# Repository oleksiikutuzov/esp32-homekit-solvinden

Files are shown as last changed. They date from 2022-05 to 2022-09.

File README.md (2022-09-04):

# esp32-homekit-led-strip
Native Apple HomeKit via an ESP32 for the IKEA SOLVINDEN lamp



Software is based on the [HomeSpan](https://github.com/HomeSpan/HomeSpan) library. Supports RGB or RGBW Neopixel LEDs.

_As usual, don't expect any warranties. I am just a hobbyist, not a professional. It works for me, but you take your own risk using it. I am not liable for any damage to your devices._

## Hardware

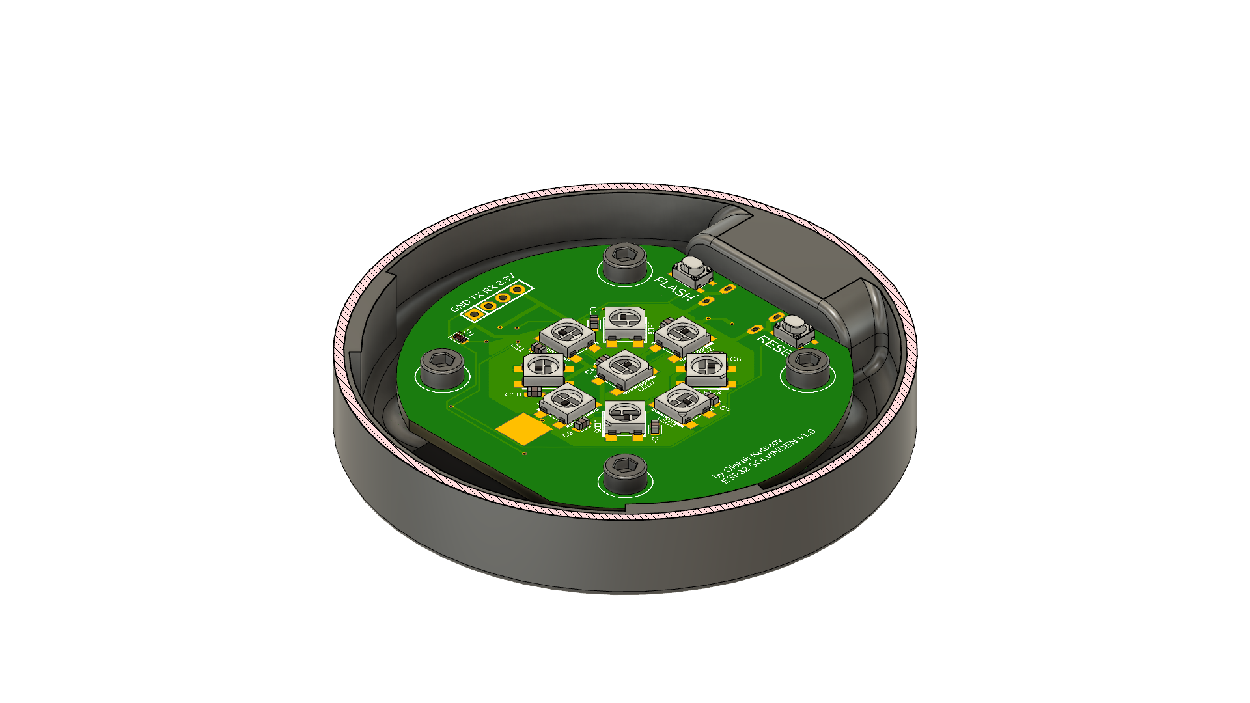
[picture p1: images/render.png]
render
 

Custom PCB is designed for the project as well as a replacement base for the lamp. The base has holes for M3 threaded inserts.

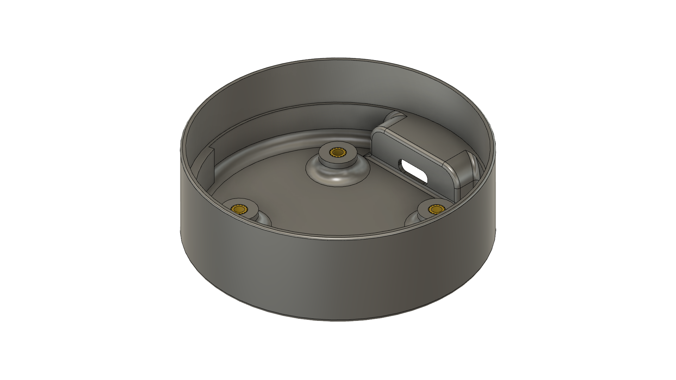
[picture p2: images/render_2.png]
render 2
 

From the original lamp, you only need the top part, which is good for diffusion. Be careful not to scratch it, as it sits pretty tight because the device is sealed.

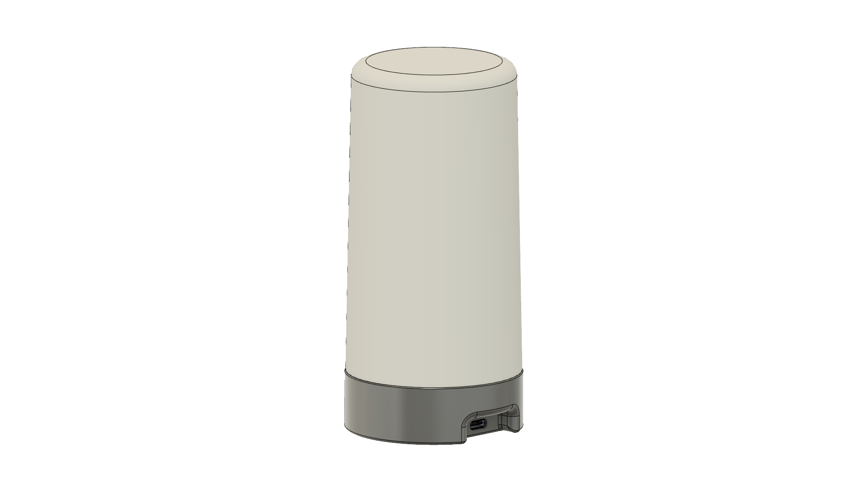
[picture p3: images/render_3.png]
render 3


## HomeKit functions

The device has two modes, which can be switched via the Eve app:
* Manual Control (manually set one single color)
* Rainbow (the device is changing colors)

*As they are custom characteristics, they are not visible in the Home app*

Characteristics values are saved to NVS, so they will be restored if the device loses power. 

## Software

Here you can see, which pins are used and pre-defined in the firmware:
```c++
 *                ESP-WROOM-32 Utilized pins
 *              ╔═════════════════════════════╗
 *              ║┌─┬─┐  ┌──┐  ┌─┐             ║
 *              ║│ | └──┘  └──┘ |             ║
 *              ║│ |            |             ║
 *              ╠═════════════════════════════╣
 *          +++ ║GND                       GND║ +++
 *          +++ ║3.3V                     IO23║ USED_FOR_NOTHING
 *              ║                         IO22║
 *              ║IO36                      IO1║ TX
 *              ║IO39                      IO3║ RX
 *              ║IO34                     IO21║
 *              ║IO35                         ║ NC
 *      RED_LED ║IO32                     IO19║
 *              ║IO33                     IO18║ 
 *              ║IO25                      IO5║
 *              ║IO26                     IO17║ NEOPIXEL
 *              ║IO27                     IO16║
 *              ║IO14                      IO4║
 *              ║IO12                      IO0║ +++, BUTTON
 *              ╚═════════════════════════════╝
```

The firmware can be built and flashed using the Arduino IDE.

For this, you will need to add ESP32 support to it.

Furthermore, you will also need to install the following libraries using the Library Manager:

* HomeSpan

And some libraries manually:

1. Go to this GitHub repo and download it as a ZIP - [ElegantOTA](https://github.com/ayushsharma82/ElegantOTA)
2. In Arduino IDE select "Sketch" -> "Include Library" and "Add .ZIP Library..." and select downloaded ZIP
3. Download and open this repository in Arduino IDE (or VSCode with Arduino extension)
4. Set the upload speed to 115200
5. Build, flash, and you're done

Instead of Arduino IDE OTA, the webserver update was implemented. You can flash binary at `http://[DEVICE IP]/update`.
There is a reboot link. Opening `http://[DEVICE IP]/reboot` will force the device to reboot. 

The device can also be controlled by the FLASH button on the board. More on [HomeSpan docs](https://github.com/HomeSpan/HomeSpan/blob/master/docs/UserGuide.md)

## Connect to HomeKit

1. Plug your LED Controller to power.
2. Press the FLASH button until the LED starts blinking rapidly and release it. Now it is in the configuration mode (More on [HomeSpan docs](https://github.com/HomeSpan/HomeSpan/blob/master/docs/UserGuide.md)). Press it two more times until the LED starts blinking 3 times in a row. This means mode 3 is chosen. Hold the button for 3-4 seconds once again and the WiFi AP will be started.
3. Go to WiFi settings on your iPhone/iPad and connect to the "HomeSpan-Setup" WiFi network.
4. You will choose your WiFi network and set the setup code for the accessory. 
5. Go to your Home app and select "Add Accessory"
6. Select "More Options" and you should see your LED Controller there.

## Todo

- [ ] Add physical button to control the device
- [ ] Add level shifter to the PCB for 5V on the data line for RGBW leds  

## References and sources

- @HomeSpan for ESP32 HomeKit firmware [GitHub link](https://github.com/HomeSpan/HomeSpan)

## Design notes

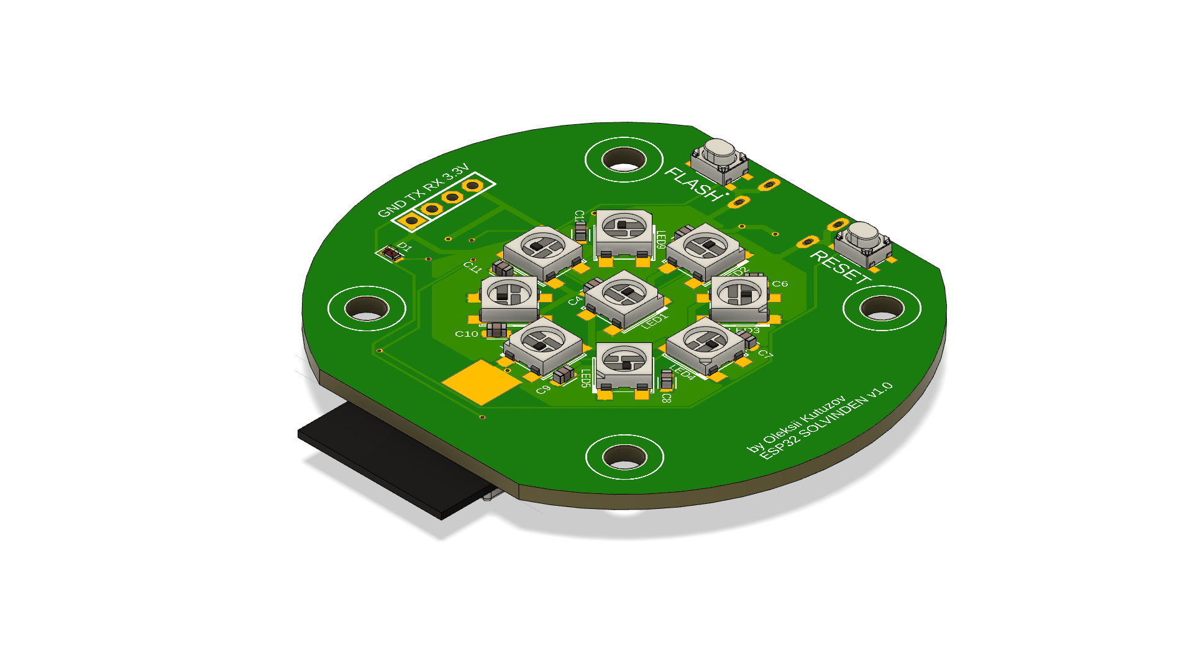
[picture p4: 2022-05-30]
PCB/PCB_TOP_1.0.png

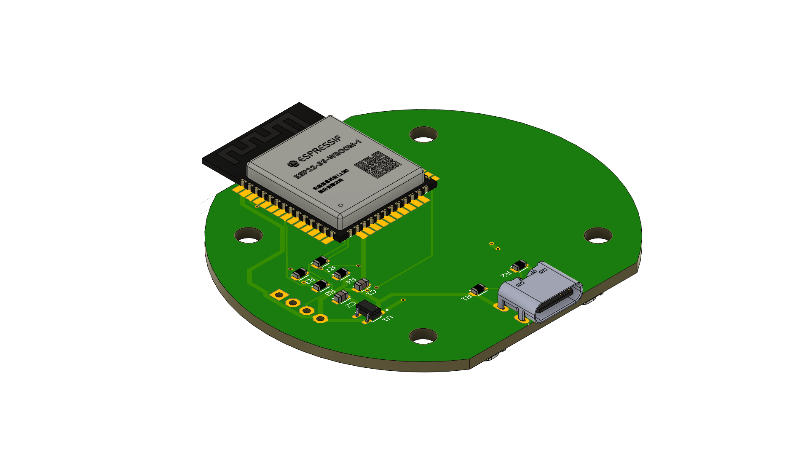
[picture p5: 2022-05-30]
PCB/PCB_BOTTOM_1.0.png

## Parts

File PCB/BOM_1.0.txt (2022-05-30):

Part Value             Device                   Package               Description                                                                  AVAILABILITY CATEGORY  
C1   10uF              C_CHIP-0603(1608-METRIC) CAPC1608X85           Capacitor - Generic                                                                       Capacitor 
C2   10uF              C_CHIP-0603(1608-METRIC) CAPC1608X85           Capacitor - Generic                                                                       Capacitor 
C4   0.1uF             C_CHIP-0603(1608-METRIC) CAPC1608X85           Capacitor - Generic                                                                       Capacitor 
C5   0.1uF             C_CHIP-0603(1608-METRIC) CAPC1608X85           Capacitor - Generic                                                                       Capacitor 
C6   0.1uF             C_CHIP-0603(1608-METRIC) CAPC1608X85           Capacitor - Generic                                                                       Capacitor 
C7   0.1uF             C_CHIP-0603(1608-METRIC) CAPC1608X85           Capacitor - Generic                                                                       Capacitor 
C8   0.1uF             C_CHIP-0603(1608-METRIC) CAPC1608X85           Capacitor - Generic                                                                       Capacitor 
C9   0.1uF             C_CHIP-0603(1608-METRIC) CAPC1608X85           Capacitor - Generic                                                                       Capacitor 
C10  0.1uF             C_CHIP-0603(1608-METRIC) CAPC1608X85           Capacitor - Generic                                                                       Capacitor 
C11  0.1uF             C_CHIP-0603(1608-METRIC) CAPC1608X85           Capacitor - Generic                                                                       Capacitor 
C12  0.1uF             C_CHIP-0603(1608-METRIC) CAPC1608X85           Capacitor - Generic                                                                       Capacitor 
D1   LED               CHIP-FLAT-R_0603-0.80MM  LEDC1608X80N_FLAT-R                                                                                             LED       
J1   USB4125-GF-A_REVA USB4125-GF-A_REVA        GCT_USB4125-GF-A_REVA USB 2.0 Type C Receptacle, Horizontal, SMT, For Power charging  Check prices Warning                
J2   F-1X04-SIP-100-40 F-1X04-SIP-100-40        SIP-100-04-40         FEMALE HEADER                                                                                       
LED1                   SK6812_5050W             LED5050_W                                                                                                                  
LED2                   SK6812_5050W             LED5050_W                                                                                                                  
LED3                   SK6812_5050W             LED5050_W                                                                                                                  
LED4                   SK6812_5050W             LED5050_W                                                                                                                  
LED5                   SK6812_5050W             LED5050_W                                                                                                                  
LED6                   SK6812_5050W             LED5050_W                                                                                                                  
LED7                   SK6812_5050W             LED5050_W                                                                                                                  
LED8                   SK6812_5050W             LED5050_W                                                                                                                  
LED9                   SK6812_5050W             LED5050_W                                                                                                                 
R1   5.1k              R_CHIP-0603(1608-METRIC) RESC1608X60           Resistor Fixed - Generic                                                                  Resistor  
R2   5.1k              R_CHIP-0603(1608-METRIC) RESC1608X60           Resistor Fixed - Generic                                                                  Resistor  
R3   4.7K              R_CHIP-0603(1608-METRIC) RESC1608X60           Resistor Fixed - Generic                                                                  Resistor  
R4   4.7K              R_CHIP-0603(1608-METRIC) RESC1608X60           Resistor Fixed - Generic                                                                  Resistor  
R7   300-500 ohm       R_CHIP-0603(1608-METRIC) RESC1608X60           Resistor Fixed - Generic                                                                  Resistor  
R8   430               R_CHIP-0603(1608-METRIC) RESC1608X60           Resistor Fixed - Generic                                                                  Resistor  
S1   SKRPACE010        SKRPACE010               SW_SKRPACE010         Switch Tactile N.O. SPST Button J-Bend 0.05A 16VDC 2.55N SMD Automotive T/R                         
S2   SKRPACE010        SKRPACE010               SW_SKRPACE010         Switch Tactile N.O. SPST Button J-Bend 0.05A 16VDC 2.55N SMD Automotive T/R                         
U1   AP2112K-3.3TRG1   AP2112K-3.3TRG1          SOT95P285X140-5N      AP2112 Series 0.6 A 3.3 V Fixed Output SMT LDO Linear Regulator - SOT23-5                           
U2   ESP32-WROOM       ESP32-WROOM              ESP32-WROOM

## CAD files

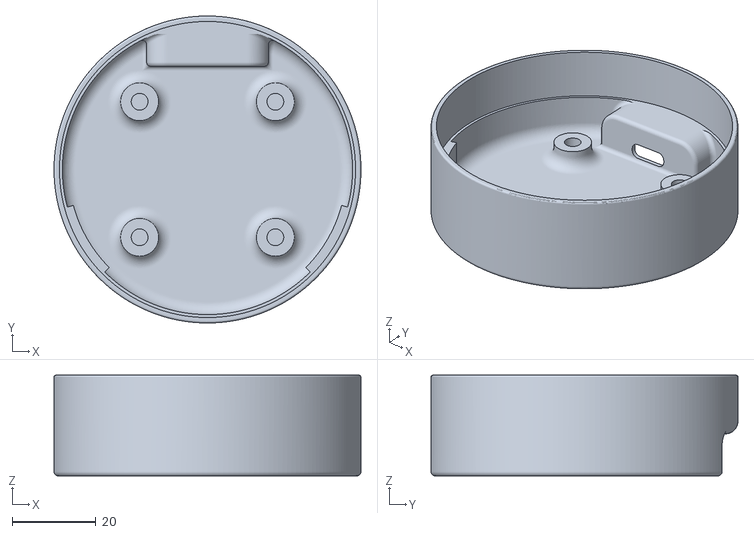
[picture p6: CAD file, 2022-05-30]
BASE/BASE.stl
73.1 x 73.1 x 24.0

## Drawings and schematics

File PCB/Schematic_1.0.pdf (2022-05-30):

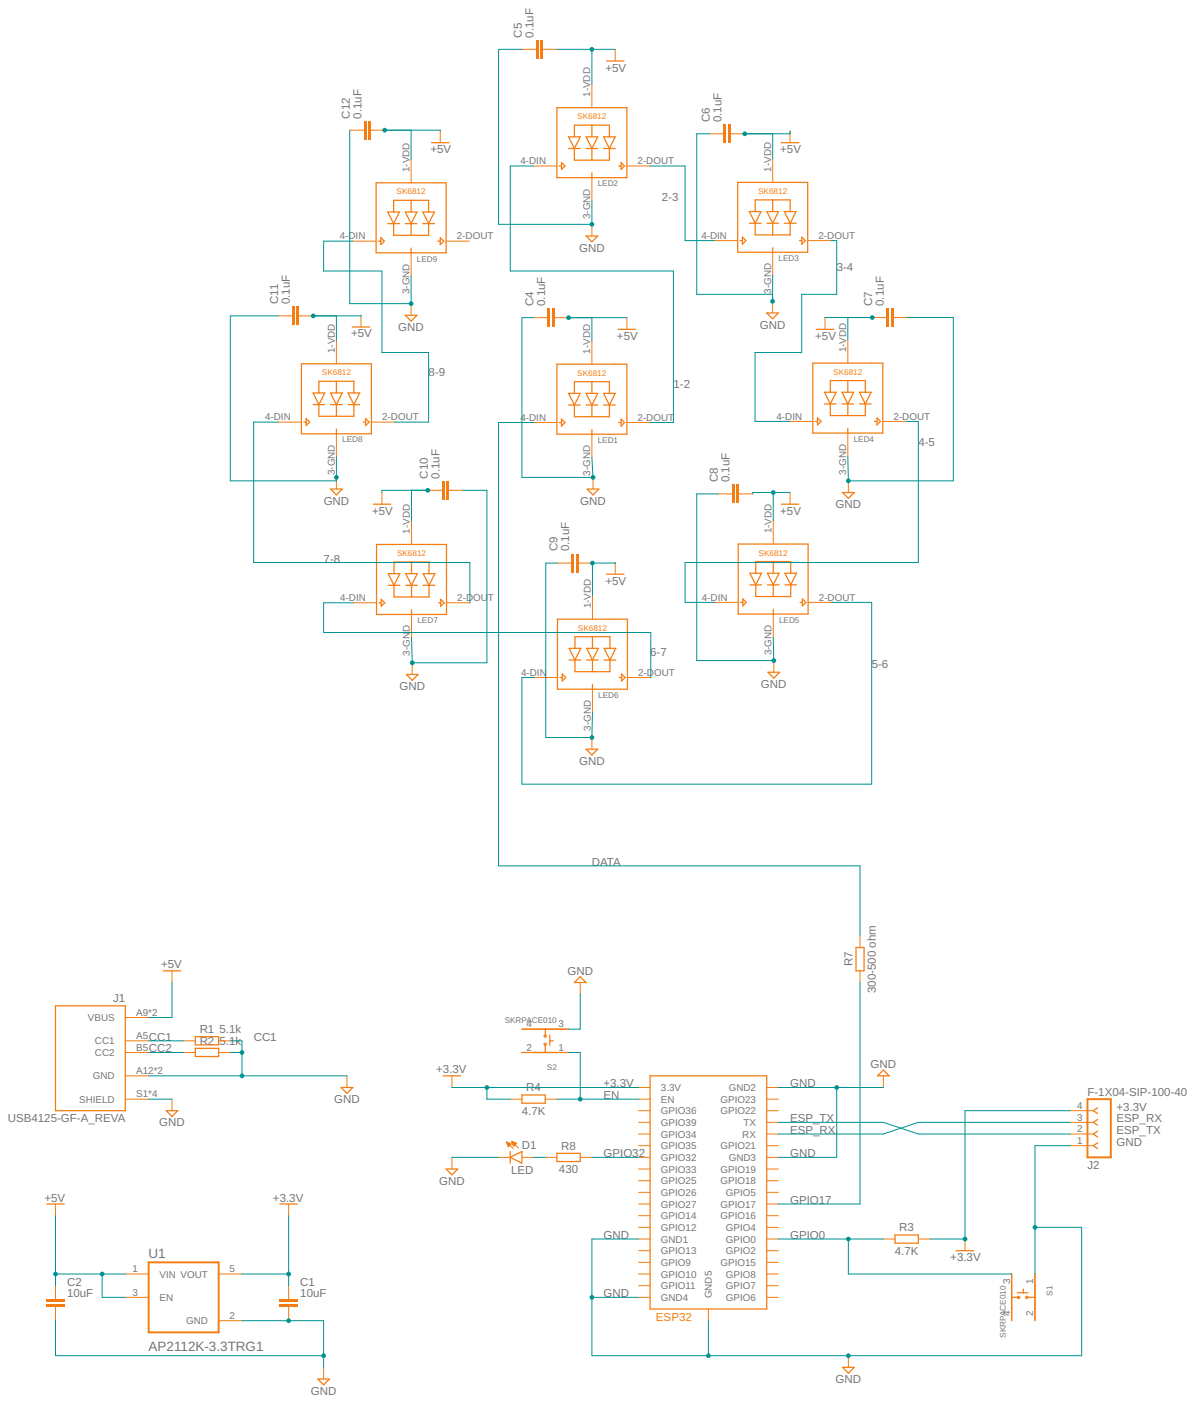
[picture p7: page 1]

GND GND

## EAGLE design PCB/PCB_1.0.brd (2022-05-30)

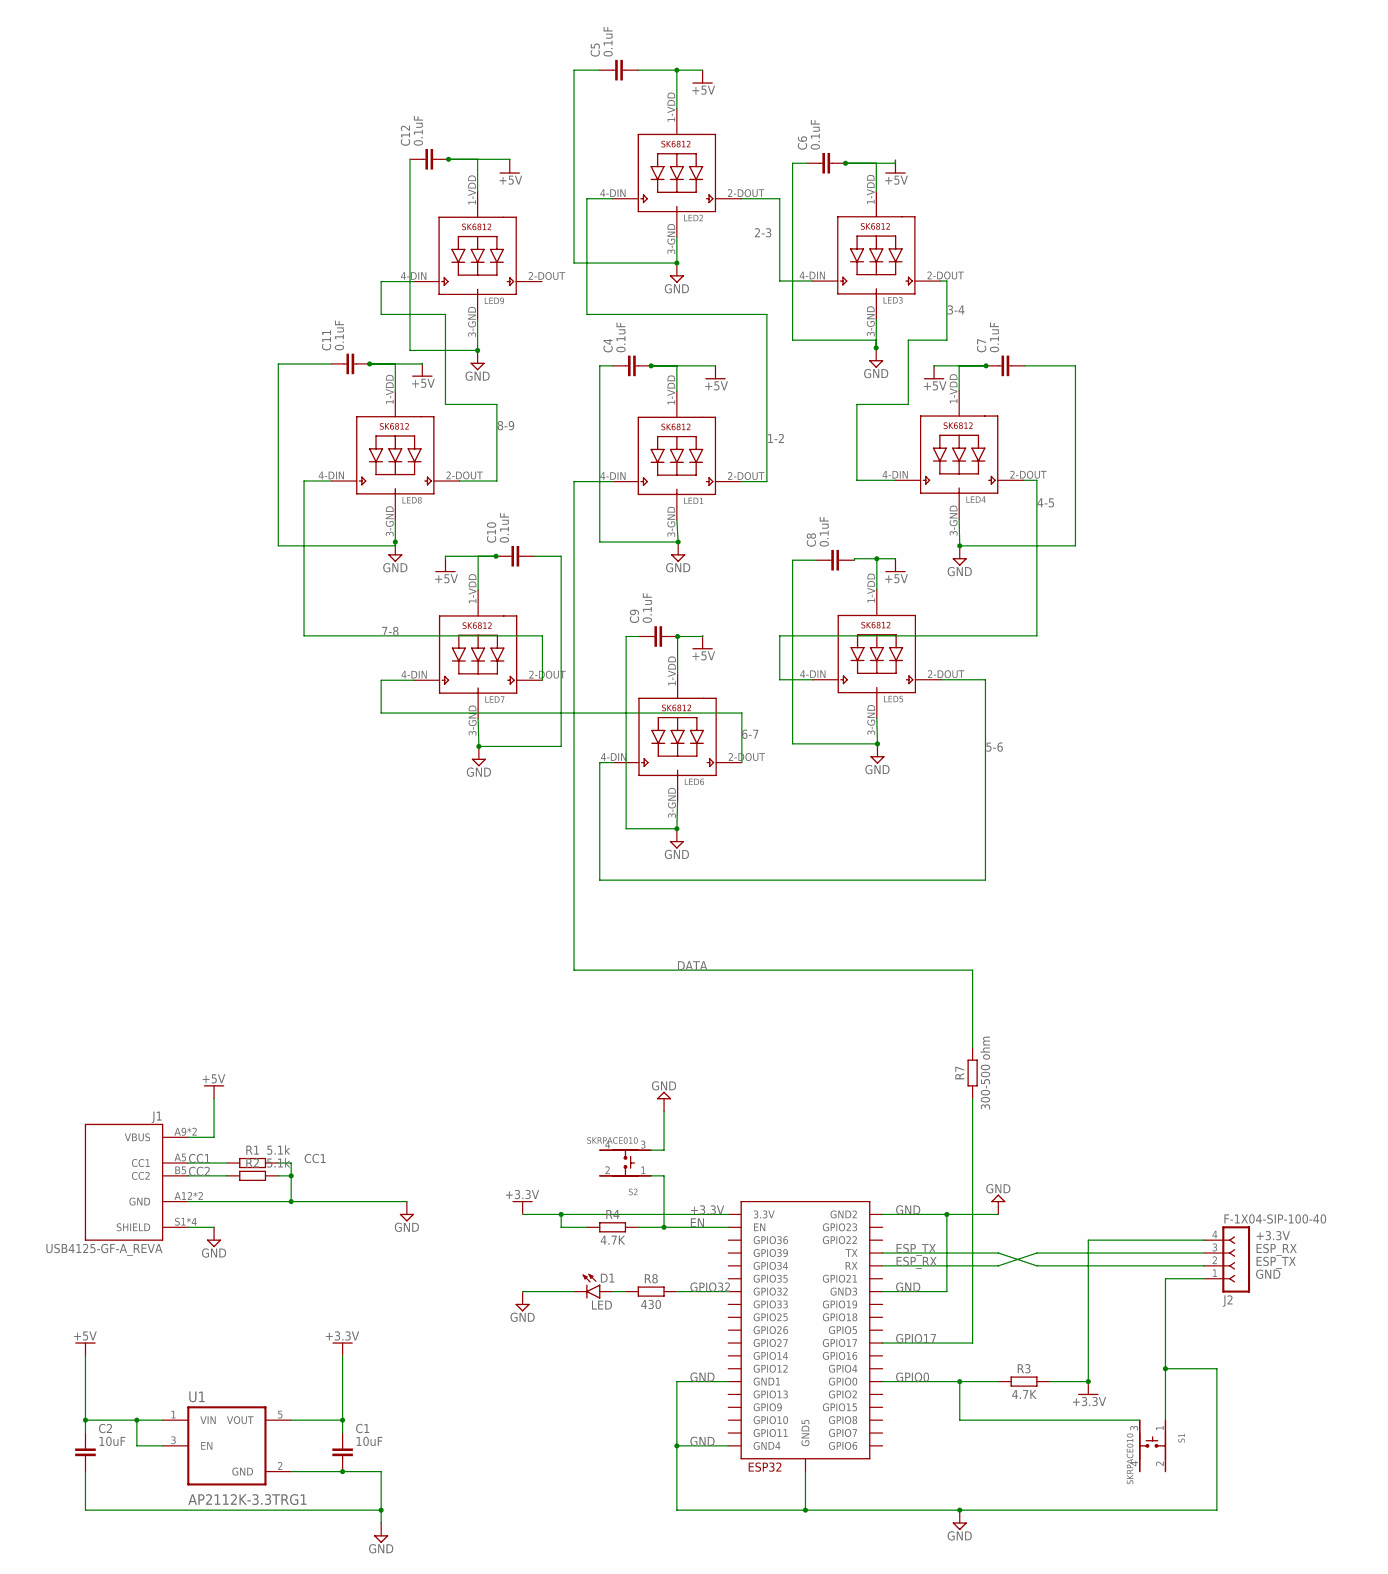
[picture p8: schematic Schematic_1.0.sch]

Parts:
C1, C2: 10uF; CAPC1608X85
C4, C5, C6, C7, C8, C9, C10, C11, C12: 0.1uF; CAPC1608X85
D1: LED; LEDC1608X80N_FLAT-R
J1: USB4125-GF-A_REVA; GCT_USB4125-GF-A_REVA
J2: F-1X04-SIP-100-40; SIP-100-04-40
LED1, LED2, LED3, LED4, LED5, LED6, LED7, LED8, LED9: SK6812_5050W; LED5050_W
R1, R2: 5.1k; RESC1608X60
R3, R4: 4.7K; RESC1608X60
R7: 300-500 ohm; RESC1608X60
R8: 430; RESC1608X60
S1, S2: SKRPACE010; SW_SKRPACE010
U1: AP2112K-3.3TRG1; SOT95P285X140-5N
U2: ESP32-WROOM

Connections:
1-2: LED1.2-DOUT (DO), LED2.4-DIN (DI)
2-3: LED2.2-DOUT (DO), LED3.4-DIN (DI)
3-4: LED3.2-DOUT (DO), LED4.4-DIN (DI)
4-5: LED4.2-DOUT (DO), LED5.4-DIN (DI)
5-6: LED5.2-DOUT (DO), LED6.4-DIN (DI)
6-7: LED6.2-DOUT (DO), LED7.4-DIN (DI)
7-8: LED7.2-DOUT (DO), LED8.4-DIN (DI)
8-9: LED8.2-DOUT (DO), LED9.4-DIN (DI)
+3.3V: C1.1, J2.4, R3.2, R4.1, U1.5 (VOUT), U2.3V3 (3.3V)
+5V: C2.1, C4.2, C5.2, C6.2, C7.1, C8.2, C9.2, C10.1, C11.2, C12.2, J1.A9 (VBUS), J1.B9 (VBUS), LED1.1-VDD (VDD), LED2.1-VDD (VDD), LED3.1-VDD (VDD), LED4.1-VDD (VDD), LED5.1-VDD (VDD), LED6.1-VDD (VDD), LED7.1-VDD (VDD), LED8.1-VDD (VDD), LED9.1-VDD (VDD), U1.1 (VIN), U1.3 (EN)
CC1: J1.A5 (CC1), R1.1
CC2: J1.B5 (CC2), R2.1
DATA: LED1.4-DIN (DI), R7.2
EN: R4.2, S2.1, U2.EN
ESP_RX: J2.3, U2.RX
ESP_TX: J2.2, U2.TX
GND: C1.2, C2.2, C4.1, C5.1, C6.1, C7.2, C8.1, C9.1, C10.2, C11.1, C12.1, D1.C, J1.A12 (GND), J1.B12 (GND), J1.S1 (SHIELD), J1.S2 (SHIELD), J1.S3 (SHIELD), J1.S4 (SHIELD), J2.1, LED1.3-GND (GND), LED2.3-GND (GND), LED3.3-GND (GND), LED4.3-GND (GND), LED5.3-GND (GND), LED6.3-GND (GND), LED7.3-GND (GND), LED8.3-GND (GND), LED9.3-GND (GND), R1.2, R2.2, S1.1, S2.3, U1.2 (GND), U2.GND1, U2.GND2, U2.GND3, U2.GND4, U2.GND5
GPIO0: R3.1, S1.3, U2.IO0 (GPIO0)
GPIO17: R7.1, U2.IO17 (GPIO17)
GPIO32: R8.2, U2.IO32 (GPIO32)
LED: D1.A, R8.1

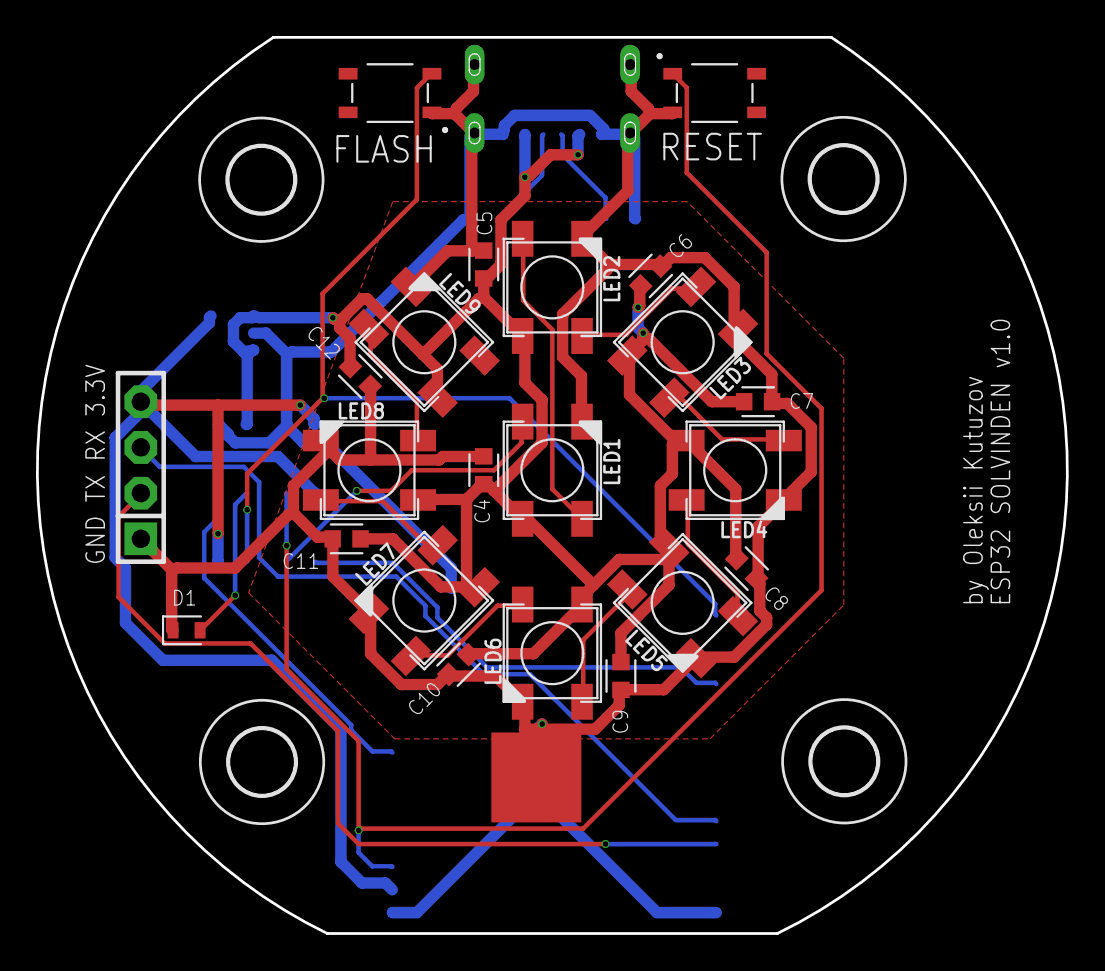
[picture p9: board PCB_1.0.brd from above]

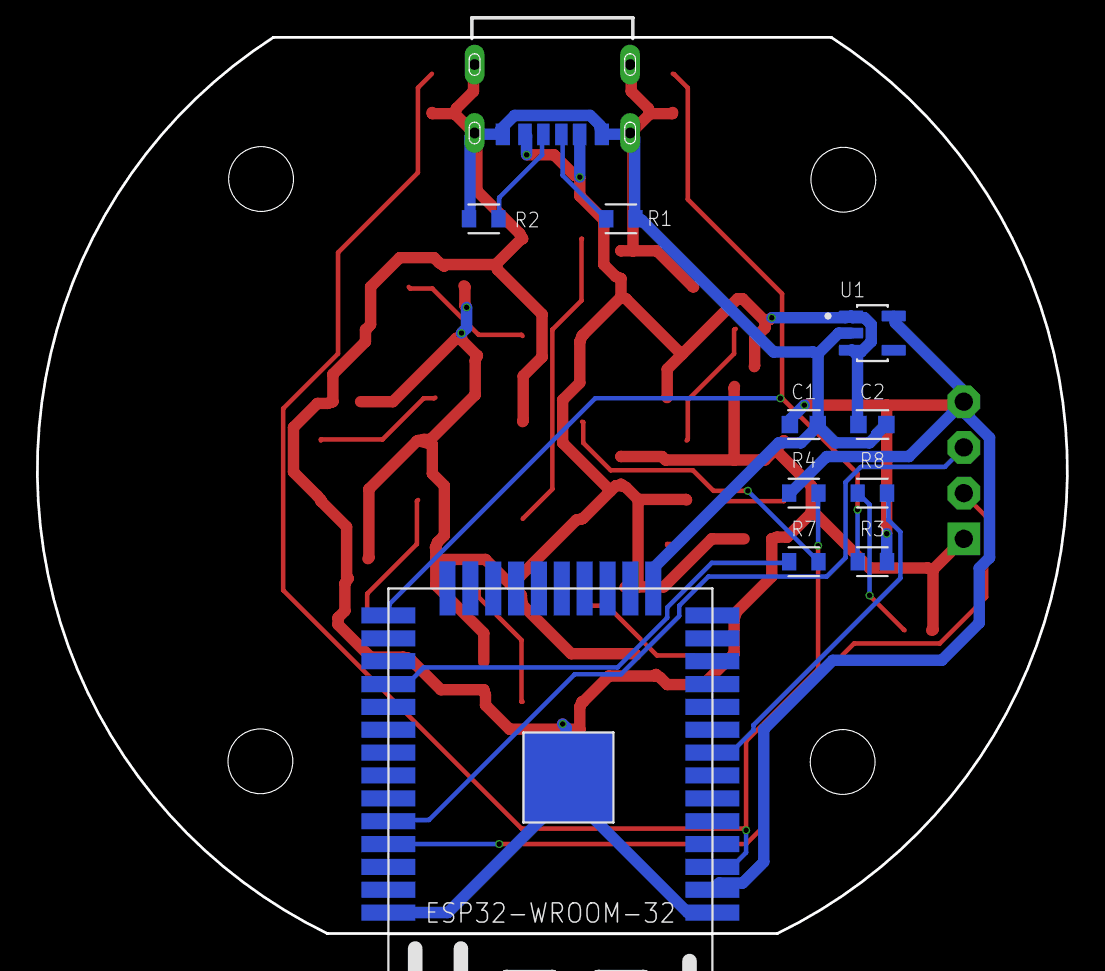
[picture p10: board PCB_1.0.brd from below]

Board: 2 copper layers, 57.2 x 49.8 mm, 37 parts (11 on the bottom side), 21 nets.

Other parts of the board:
H3, H5, H7, H9: MOUNT-HOLE3.6; 3,6

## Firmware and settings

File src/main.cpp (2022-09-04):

/*********************************************************************************
 *  MIT License
 *
 *  Copyright (c) 2022 Gregg E. Berman
 *
 *  https://github.com/HomeSpan/HomeSpan
 *
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
 ********************************************************************************/

/*
 *                ESP-WROOM-32 Utilized pins
 *              ╔═════════════════════════════╗
 *              ║┌─┬─┐  ┌──┐  ┌─┐             ║
 *              ║│ | └──┘  └──┘ |             ║
 *              ║│ |            |             ║
 *              ╠═════════════════════════════╣
 *          +++ ║GND                       GND║ +++
 *          +++ ║3.3V                     IO23║ USED_FOR_NOTHING
 *              ║                         IO22║
 *              ║IO36                      IO1║ TX
 *              ║IO39                      IO3║ RX
 *              ║IO34                     IO21║
 *              ║IO35                         ║ NC
 *      RED_LED ║IO32                     IO19║
 *              ║IO33                     IO18║ RELAY
 *              ║IO25                      IO5║
 *              ║IO26                     IO17║ NEOPIXEL_RGB
 *              ║IO27                     IO16║ NEOPIXEL_RGBW
 *              ║IO14                      IO4║
 *              ║IO12                      IO0║ +++, BUTTON
 *              ╚═════════════════════════════╝
 */

float angle = 0;

#define REQUIRED VERSION(1, 6, 0) // Required HomeSpan version

#include "HomeSpan.h"
#include "extras/Pixel.h"
#include <WiFiClient.h>
#include <WebServer.h>
#include <ElegantOTA.h>
#include "OTA.hpp"

#if defined(CONFIG_IDF_TARGET_ESP32)

#if RGBW
// Data from gpio 16 is going through the level shifter to increase the control voltage to 5V
#define NEOPIXEL_PIN 16
#else
// Data from gpio 17 is directly connected to the neopixel, fine for RGB strips
#define NEOPIXEL_PIN 17
#endif

#elif defined(CONFIG_IDF_TARGET_ESP32S2)

#define NEOPIXEL_PIN 38

#elif defined(CONFIG_IDF_TARGET_ESP32C3)

#define NEOPIXEL_PIN 2

#endif

// clang-format off
CUSTOM_CHAR(RainbowEnabled, 00000001-0001-0001-0001-46637266EA00, PR + PW + EV, BOOL, 0, 0, 1, false);
// clang-format on

WebServer server(80);

void setupWeb();

char sNumber[18] = "11:11:11:11:11:11";

struct Pixel_Strand : Service::LightBulb { // Addressable RGBW Pixel Strand of nPixel Pixels

	struct SpecialEffect {
		Pixel_Strand *px;
		const char	 *name;

		SpecialEffect(Pixel_Strand *px, const char *name) {
			this->px   = px;
			this->name = name;
			Serial.printf("Adding Effect %d: %s\n", px->Effects.size() + 1, name);
		}

		virtual void	 init() {}
		virtual uint32_t update() { return (60000); }
		virtual int		 requiredBuffer() { return (0); }
	};

	Characteristic::On			   power{0, true};
	Characteristic::Hue			   H{0, true};
	Characteristic::Saturation	   S{100, true};
	Characteristic::Brightness	   V{100, true};
	Characteristic::RainbowEnabled rainbow{false, true};

	vector<SpecialEffect *> Effects;

	Pixel		 *pixel;
	int			  nPixels;
	Pixel::Color *colors;
	uint32_t	  alarmTime;

	Pixel_Strand(int pin, int nPixels) : Service::LightBulb() {

		pixel		  = new Pixel(pin, RGBW); // creates RGB/RGBW pixel LED on specified pin using default timing parameters suitable for most SK68xx LEDs
		this->nPixels = nPixels;			  // store number of Pixels in Strand

		Effects.push_back(new ManualControl(this));
		Effects.push_back(new Rainbow(this));

		rainbow.setUnit(""); // configures custom "RainbowEnabled" characteristic for use with Eve HomeKit
		rainbow.setDescription("Rainbow Animation");

		V.setRange(5, 100, 1); // sets the range of the Brightness to be from a min of 5%, to a max of 100%, in steps of 1%

		int bufSize = 0;

		for (int i = 0; i < Effects.size(); i++)
			bufSize = Effects[i]->requiredBuffer() > bufSize ? Effects[i]->requiredBuffer() : bufSize;

		colors = (Pixel::Color *)calloc(bufSize, sizeof(Pixel::Color)); // storage for dynamic pixel pattern

		Serial.printf("\nConfigured Pixel_Strand on pin %d with %d pixels and %d effects.  Color buffer = %d pixels\n\n", pin, nPixels, Effects.size(), bufSize);

		update();
	}

	boolean update() override {

		if (!power.getNewVal()) {
			pixel->set(Pixel::Color().RGB(0, 0, 0, 0), this->nPixels);
		} else if (!rainbow.getNewVal()) {
			Effects[0]->init();
			if (rainbow.updated())
				Serial.printf("Effect changed to: %s\n", Effects[0]->name);
		} else {
			Effects[1]->init();
			alarmTime = millis() + Effects[1]->update();
			if (rainbow.updated())
				Serial.printf("Effect changed to: %s\n", Effects[1]->name);
		}
		return (true);
	}

	void
	loop() override {

		if (millis() > alarmTime && power.getVal())
			if (rainbow.getVal()) {
				alarmTime = millis() + Effects[1]->update();
			}
	}

	//////////////

	struct ManualControl : SpecialEffect {

		ManualControl(Pixel_Strand *px) : SpecialEffect{px, "Manual Control"} {}

		void init() override {

			float h = px->H.getNewVal();
			float s = px->S.getNewVal();
			float v = px->V.getNewVal();

#if RGBW
			if (h == 30) {
				px->pixel->set(
					Pixel::Color().HSV(h, s, 0, v), px->nPixels);
			} else {
				px->pixel->set(
					Pixel::Color().HSV(h, s, v), px->nPixels);
			}
#else
			px->pixel->set(
				Pixel::Color().HSV(h, s, v), px->nPixels);
#endif
		}
	};

	//////////////
	struct Rainbow : SpecialEffect {

		int8_t *dir;

		Rainbow(Pixel_Strand *px) : SpecialEffect{px, "Rainbow"} {
			dir = (int8_t *)calloc(px->nPixels, sizeof(int8_t));
		}

		void init() override {
			for (int i = 0; i < px->nPixels; i++) {
				px->colors[i].RGB(0, 0, 0, 0);
				dir[i] = 0;
			}
		}

		uint32_t update() override {
			float value = px->V.getNewVal<float>();
			for (int i = 0; i < px->nPixels; i++) {
				px->colors[i] = Pixel::Color().HSV(angle, 100, value);
			}
			px->pixel->set(px->colors, px->nPixels);
			angle++;
			if (angle == 360) angle = 0;
			return (100);
		}

		int requiredBuffer() override { return (px->nPixels); }
	};
};

struct DEV_Switch : Service::Switch {

	int					ledPin; // relay pin
	SpanCharacteristic *power;

	// Constructor
	DEV_Switch(int ledPin) : Service::Switch() {
		power		 = new Characteristic::On(0, true);
		this->ledPin = ledPin;
		pinMode(ledPin, OUTPUT);

		digitalWrite(ledPin, power->getVal());
	}

	// Override update method
	boolean update() {
		digitalWrite(ledPin, power->getNewVal());

		return (true);
	}
};

///////////////////////////////

void setup() {

	Serial.begin(115200);

	Serial.print("Active firmware version: ");
	Serial.println(FirmwareVer);

	String mode;
#if RGBW
	mode = "-RGBW ";
#else
	mode = "-RGB ";
#endif

	String	   temp			  = FW_VERSION;
	const char compile_date[] = __DATE__ " " __TIME__;
	char	  *fw_ver		  = new char[temp.length() + 30];
	strcpy(fw_ver, temp.c_str());
	strcat(fw_ver, mode.c_str());
	strcat(fw_ver, " (");
	strcat(fw_ver, compile_date);
	strcat(fw_ver, ")");

	for (int i = 0; i < 17; ++i) // we will iterate through each character in WiFi.macAddress() and copy it to the global char sNumber[]
	{
		sNumber[i] = WiFi.macAddress()[i];
	}
	sNumber[17] = '\0'; // the last charater needs to be a null

	homeSpan.setSketchVersion("1.0.0");								// set sketch version
	homeSpan.setLogLevel(0);										// set log level to 0 (no logs)
	homeSpan.setStatusPin(32);										// set the status pin to GPIO32
	homeSpan.setStatusAutoOff(10);									// disable led after 10 seconds
	homeSpan.setWifiCallback(setupWeb);								// Set the callback function for wifi events
	homeSpan.reserveSocketConnections(5);							// reserve 5 socket connections for Web Server
	homeSpan.setControlPin(0);										// set the control pin to GPIO0
	homeSpan.setPortNum(88);										// set the port number to 81
	homeSpan.enableAutoStartAP();									// enable auto start of AP
	homeSpan.enableWebLog(10, "pool.ntp.org", "UTC-2:00", "myLog"); // enable Web Log
	homeSpan.setSketchVersion(fw_ver);

	homeSpan.begin(Category::Lighting, "SOLVINDEN");

	new SpanAccessory(1);
	new Service::AccessoryInformation();
	new Characteristic::Name("SOLVINDEN");
	new Characteristic::Manufacturer("HomeSpan");
	new Characteristic::SerialNumber(sNumber);
#if RGBW
	new Characteristic::Model("NeoPixel RGBW LEDs");
#else
	new Characteristic::Model("NeoPixel RGB LEDs");
#endif
	new Characteristic::FirmwareRevision(temp.c_str());
	new Characteristic::Identify();

	new Service::HAPProtocolInformation();
	new Characteristic::Version("1.1.0");

	new Pixel_Strand(NEOPIXEL_PIN, 9);
}

///////////////////////////////

void loop() {
	homeSpan.poll();
	server.handleClient();
	repeatedCall();
}

///////////////////////////////

void setupWeb() {
	server.on("/metrics", HTTP_GET, []() {
		double uptime		= esp_timer_get_time() / (6 * 10e6);
		double heap			= esp_get_free_heap_size();
		String uptimeMetric = "# HELP uptime Solvinden uptime\nhomekit_uptime{device=\"solvinden\",location=\"home\"} " + String(int(uptime));
		String heapMetric	= "# HELP heap Available heap memory\nhomekit_heap{device=\"solvinden\",location=\"home\"} " + String(int(heap));

		Serial.println(uptimeMetric);
		Serial.println(heapMetric);
		server.send(200, "text/plain", uptimeMetric + "\n" + heapMetric);
	});

	server.on("/reboot", HTTP_GET, []() {
		String content = "<html><body>Rebooting!  Will return to configuration page in 10 seconds.<br><br>";
		content += "<meta http-equiv = \"refresh\" content = \"10; url = /\" />";
		server.send(200, "text/html", content);

		ESP.restart();
	});

	ElegantOTA.begin(&server); // Start ElegantOTA
	server.begin();
	LOG1("HTTP server started");
} // setupWeb

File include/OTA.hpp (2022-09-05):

#include <WiFi.h>
#include <HTTPClient.h>
#include <HTTPUpdate.h>
#include <WiFiClientSecure.h>
#include "cert.hpp"
#include <HomeSpan.h>

#define FW_VERSION	   "1.2.4"
// #define RGBW		   // defined = RGBW, not defined = RGB: defined in platformio.ini

#define URL_fw_Version "https://raw.githubusercontent.com/oleksiikutuzov/esp32-homekit-solvinden/main/bin_version.txt"

#if RGBW
#define URL_fw_Bin "https://raw.githubusercontent.com/oleksiikutuzov/esp32-homekit-solvinden/main/esp32_solvinden_rgbw.bin"
#else
#define URL_fw_Bin "https://raw.githubusercontent.com/oleksiikutuzov/esp32-homekit-solvinden/main/esp32_solvinden_rgb.bin"
#endif

String fw_ver	   = FW_VERSION;
String FirmwareVer = {
	fw_ver};

void firmwareUpdate();
int	 FirmwareVersionCheck();

unsigned long previousMillis = 0;			   // will store last time LED was updated
const long	  interval		 = 60 * 60 * 1000; // 1 hour in ms

void repeatedCall() {
	static int	  num			= 0;
	unsigned long currentMillis = millis();

	if ((currentMillis - previousMillis) >= interval) {
		// save the last time you blinked the LED
		previousMillis = currentMillis;
		if (FirmwareVersionCheck()) {
			firmwareUpdate();
		}
	}
}

void firmwareUpdate(void) {
	WiFiClientSecure client;
	client.setCACert(rootCACertificate);
	t_httpUpdate_return ret = httpUpdate.update(client, URL_fw_Bin);

	switch (ret) {
	case HTTP_UPDATE_FAILED:
		LOG1("HTTP_UPDATE_FAILED Error (%d): %s\n", httpUpdate.getLastError(), httpUpdate.getLastErrorString().c_str());
		break;

	case HTTP_UPDATE_NO_UPDATES:
		LOG1("HTTP_UPDATE_NO_UPDATES");
		break;

	case HTTP_UPDATE_OK:
		LOG1("HTTP_UPDATE_OK");
		break;
	}
}

int FirmwareVersionCheck(void) {
	String payload;
	int	   httpCode;
	String fwurl = "";
	fwurl += URL_fw_Version;
	fwurl += "?";
	fwurl += String(rand());
	Serial.println(fwurl);
	WiFiClientSecure *client = new WiFiClientSecure;

	if (client) {
		client->setCACert(rootCACertificate);

		// Add a scoping block for HTTPClient https to make sure it is destroyed before WiFiClientSecure *client is
		HTTPClient https;

		if (https.begin(*client, fwurl)) { // HTTPS
			Serial.print("[HTTPS] GET...\n");
			// start connection and send HTTP header
			delay(100);
			httpCode = https.GET();
			delay(100);
			if (httpCode == HTTP_CODE_OK) // if version received
			{
				payload = https.getString(); // save received version
			} else {
				Serial.print("error in downloading version file:");
				Serial.println(httpCode);
			}
			https.end();
		}
		delete client;
	}

	if (httpCode == HTTP_CODE_OK) // if version received
	{
		payload.trim();
		if (payload.equals(FirmwareVer)) {
			Serial.printf("\nDevice already on latest firmware version:%s\n", FirmwareVer);
			return 0;
		} else {
			Serial.println(payload);
			Serial.println("New firmware detected");
			return 1;
		}
	}
	return 0;
}

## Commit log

2022-05-30 Add sketch from led_strip project
2022-05-30 Add Base 3D model
    [BASE.stl]
2022-05-30 Add more hardware files
    [PCB_v28.brd, Schematic_v1.0_v14.sch]
2022-07-08 Serial number field shows mac address of ESP32
2022-07-08 Update hardware files names
    [PCB_1.0.brd, Schematic_1.0.sch]
2022-08-09 Switch from ESPAsyncWebServer to WebServer
2022-09-03 Fix update URLs, minor adjustments
    [OTA.hpp]
2022-09-04 Switch to PlatformIO
2022-09-04 Switch to PlatformIO build

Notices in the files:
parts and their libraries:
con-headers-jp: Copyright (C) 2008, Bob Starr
